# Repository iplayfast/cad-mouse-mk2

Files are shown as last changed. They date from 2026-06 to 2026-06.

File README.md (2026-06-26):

# CAD Mouse MK2

Watch the build video ↓

[](https://youtu.be/62xlzGs8LXA)

This is the second iteration of my DIY CAD Mouse, rebuilt to behave like a real 6DoF controller. It uses a custom PCB with three magnetic sensors, a 3D printed spring, and a redesigned enclosure that is smaller and easier to build.

  Build instructions → [Instructables](https://www.instructables.com/CAD-Mouse-MK2-a-6DoF-Space-Mouse-Using-Magnets)

<sub>⚠️ There have been several comments raising concerns about the longevity of the PETG spring. If it does not last as expected, a revision of the knob design will be needed.</sub>

## Linux Setup

After flashing the firmware, run the one-time setup script to configure spacenavd (the 6DoF motion driver) and the button mapper:

```bash
./linux-setup.sh
```

This script:
- Installs `spacenavd` and `xdotool`
- Writes `/etc/spnavrc` so spacenavd recognises the device by USB VID:PID
- Installs udev rules so the device is accessible without root
- Installs `spacemouse-buttons.py` as a systemd user service that maps button presses to keystrokes

After running it, plug in the mouse and wait a couple of seconds for the LED to turn green — the device is running its zero-calibration on startup.

### Button mapping

Button behaviour is configured in `~/.config/spacemouse/button-map.conf`. The file shipped with the repo maps:

| Button | App | Key(s) |
|---|-----|---|
| 1 | FreeCAD | `2` (top view) |
| 1 | * (all others) | `f` (fit/zoom all) |
| 2 | * | `5` (isometric view) |

Edit the file to match your preferred CAD application. Reload without restarting:

```bash
kill -HUP $(cat /tmp/spacemouse-buttons.pid)
```

Live log:

```bash
journalctl --user -fu spacemouse-buttons
```

Debug button events:

```bash
python3 ~/.local/bin/spacemouse-buttons.py --list-events
```

## Calibration

Because the three magnetic sensors are physically close together, each sensor responds to motion in every direction — not just the one you're moving. Without correction, pushing the puck sideways also produces spurious tilt and twist outputs. Calibration solves this by fitting a **6×9 decoupling matrix** that maps the raw 9-channel sensor readings (3 axes × 3 sensors) to clean 6-DoF outputs (TX, TY, TZ, RX, RY, RZ).

The fitted matrix is sent to the device over USB and saved to flash — **no reflashing required**. The device loads it automatically on every boot. `firmware/include/Calibration.h` is also updated as a compiled-in fallback for fresh firmware flashes.

You should recalibrate whenever you rebuild the mouse, swap a sensor, or notice persistent drift or cross-axis bleed-through.

### Requirements

- Python 3 with `numpy` (`pip install numpy`)
- The mouse flashed and plugged in, LED solid green (idle)

### Steps

1. From the project root, run:
   ```bash
   ./run_calibration.sh
   ```
2. The script walks you through **6 movements**, one per axis:

   | Step | Movement |
   |------|----------|
   | TX | Slide the puck **left and right** — translate only, no tilt or twist |
   | TY | Slide the puck **forward and back** — translate only, no tilt or twist |
   | TZ | Press the puck **straight down** then release — no tilt or sideways |
   | RX | **Tilt front-to-back** — front edge dips then rises |
   | RY | **Tilt left-to-right** — left edge dips then rises |
   | RZ | **Twist clockwise then counterclockwise** around the puck's centre |

3. For each step: press **Enter** to open the live monitor, make the movement slowly (stay well under the ±350 output limit), then press **Q** to stop recording.
4. After all 6 logs are collected, `calibrate.py` fits the matrix and prints a cross-talk table. Any axis bleeding more than 50% into another is flagged — if you see warnings, recollect that axis's log.
5. The new matrix is sent to the device immediately and takes effect without restarting. It is also written to `firmware/include/Calibration.h`.

### How it works

**Data collection** — `monitor.py` polls HID feature report ID 4 via the Linux `hidraw` interface (`HIDIOCGFEATURE` ioctl) at ~50 Hz. The firmware fills this report with the 9 baseline-subtracted sensor delta values each motion loop cycle. Motion axis values (TX–RZ) are read from the standard HID input report. No serial port or special firmware build is required.

**Matrix fitting** — `calibrate.py` uses least-squares regression (`numpy.linalg.lstsq`) across all six labeled movement logs simultaneously to find the 6×9 matrix that best predicts the intended single-axis output from the 9 sensor deltas. Fitting all axes together lets the solver distinguish shared sensor patterns that belong to one DoF from those that belong to another.

**Sending the result** — after fitting, `calibrate.py` writes the matrix to the device via HID output report ID 5 (`write()` on the hidraw device). The firmware applies the matrix immediately and saves it to LittleFS flash. On every subsequent boot, the saved matrix is loaded automatically. If no saved matrix exists (e.g. after first flash), the firmware falls back to the matrix compiled into `Calibration.h`.

[][cc-by-nc-sa]

[][cc-by-nc-sa]

[cc-by-nc-sa]: http://creativecommons.org/licenses/by-nc-sa/4.0/
[cc-by-nc-sa-image]: https://licensebuttons.net/l/by-nc-sa/4.0/88x31.png
[cc-by-nc-sa-shield]: https://img.shields.io/badge/License-CC%20BY--NC--SA%204.0-lightgrey.svg

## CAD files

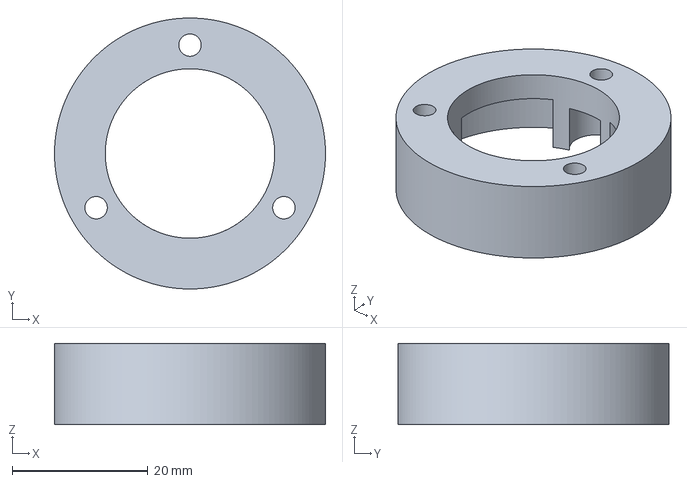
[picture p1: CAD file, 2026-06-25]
enclosure/step/Magent8mmholder.3mf
40.0 x 40.0 x 12.0 mm

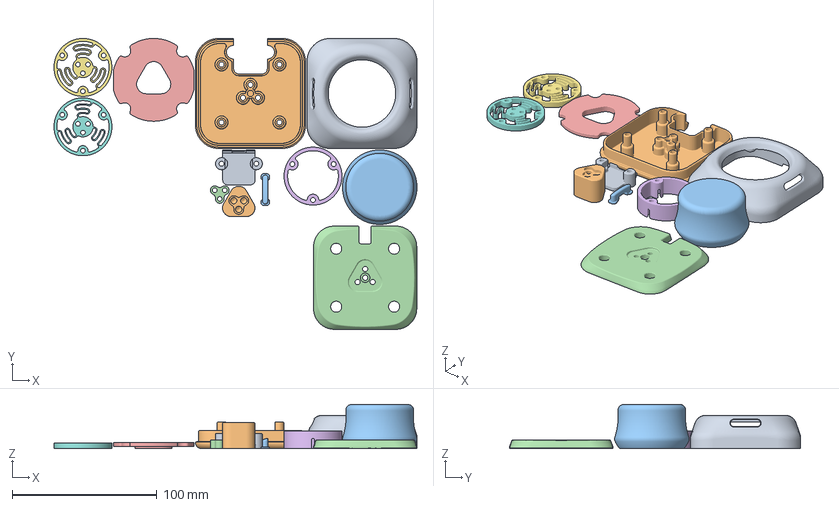
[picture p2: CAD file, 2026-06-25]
enclosure/stl/00_spring_1_0_mm_30_deg.3mf
250.7 x 201.0 x 30.5 mm
base_shell_top.stl
base_shell_bottom.stl
knob.stl
base_separator.stl
diffuser.stl
magnet_holder.stl
00_spring_1_0_mm_30_deg.stl
01_spring_0_8_mm_30_deg.stl
base_mcu_cover.stl
stem.stl
side_button.stl
spring_spacer.stl

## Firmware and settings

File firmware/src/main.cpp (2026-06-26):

#include <Arduino.h>
#include <LittleFS.h>

#include "CalibrationStore.h"
#include "Config.h"
#include "Controllers.h"
#include "StateMachine.h"

InputController inputController;
LEDController ledController;
SensorController sensorController;
MotionController motionController;
HIDController hidController;
TelemetryController telemetryController;

void setup() {
  hidController.begin();

  if (Config::ENABLE_TELEMETRY) {
    Serial.begin(115200);
    delay(200);
  }

  LittleFS.begin();

  inputController.begin();
  ledController.begin();
  sensorController.begin();
  motionController.reset();
  telemetryController.begin();

  // Load persisted calibration matrix if one has been saved.
  float matrix[6][9];
  if (CalibrationStore::load(matrix)) {
    motionController.setDecouplingMatrix(matrix);
  }

  stateMachine.changeState(&StateMachine::calibratingState);
}

void loop() {
  hidController.task();
  stateMachine.update();
}

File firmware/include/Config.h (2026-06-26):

#pragma once

#include <Arduino.h>

namespace Config {

const bool ENABLE_TELEMETRY = false;

// Hardware pins (XIAO RP2350)
const int PIN_RIGHT_BTN = D0;
const int PIN_LEFT_BTN = D2;
const int PIN_LED_DATA = D3;
const int PIN_LED_LS = D1;
const int PIN_MAG1_LS = D10;
const int PIN_MAG2_LS = D9;
const int PIN_MAG3_LS = D8;

// Samples for calibration offset
const int ZERO_SAMPLES = 200;

// Dead zones
const float DEAD_T = 16.0;
const float DEAD_R = 20.0;

// Smoothing
const float SMOOTH_TAU_S = 0.08;

// Final axis output range
const float AXIS_LIMIT = 350.0;

// RGB LEDs
const int LED_COUNT = 8;
const int LED_BRIGHTNESS = 40;
const unsigned long LED_IDLE_COLOR = 0x00FF00;
const unsigned long LED_CALIBRATING_COLOR = 0x0000FF;

// FSM timing
const long IDLE_SLEEP_TIMEOUT_MS = 2 * 60 * 1000;

}  // namespace Config

#include "Calibration.h"

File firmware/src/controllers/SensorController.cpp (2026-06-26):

#include "controllers/SensorController.h"

#include "Config.h"

using namespace ifx::tlx493d;

SensorController::SensorController()
    : mag1Sensor_(Wire, TLx493D_IIC_ADDR_A0_e),
      mag2Sensor_(Wire, TLx493D_IIC_ADDR_A0_e),
      mag3Sensor_(Wire, TLx493D_IIC_ADDR_A0_e) {}

void SensorController::powerOff(int pin) { digitalWrite(pin, LOW); }

void SensorController::powerOn(int pin) {
  digitalWrite(pin, HIGH);
  delay(5);
}

void SensorController::begin() {

  pinMode(Config::PIN_MAG1_LS, OUTPUT);
  pinMode(Config::PIN_MAG2_LS, OUTPUT);
  pinMode(Config::PIN_MAG3_LS, OUTPUT);

  // All three rails are pulled high in hardware, so force them all off first
  // before bringing sensors up one-by-one for address assignment.

  powerOff(Config::PIN_MAG1_LS);
  powerOff(Config::PIN_MAG2_LS);
  powerOff(Config::PIN_MAG3_LS);
  delay(5);

  Wire.begin();
  Wire.setClock(400000);

  powerOn(Config::PIN_MAG1_LS);
  mag1Sensor_.begin(true, false, false, true);
  mag1Sensor_.setIICAddress(TLx493D_IIC_ADDR_A2_e);
  mag1Sensor_.setSensitivity(TLx493D_EXTRA_SHORT_RANGE_e);
  delay(10);

  powerOn(Config::PIN_MAG2_LS);
  mag2Sensor_.begin(true, false, false, true);
  mag2Sensor_.setIICAddress(TLx493D_IIC_ADDR_A1_e);
  mag2Sensor_.setSensitivity(TLx493D_EXTRA_SHORT_RANGE_e);
  delay(10);

  powerOn(Config::PIN_MAG3_LS);
  mag3Sensor_.begin(true, false, false, true);
  mag3Sensor_.setSensitivity(TLx493D_EXTRA_SHORT_RANGE_e);
  delay(10);
}

bool SensorController::readRaw(float out[9]) {
  double mag1x = 0, mag1y = 0, mag1z = 0, temp1 = 0;
  double mag2x = 0, mag2y = 0, mag2z = 0, temp2 = 0;
  double mag3x = 0, mag3y = 0, mag3z = 0, temp3 = 0;

  const bool ok1 = mag1Sensor_.getMagneticFieldAndTemperature(&mag1x, &mag1y, &mag1z, &temp1);
  const bool ok2 = mag2Sensor_.getMagneticFieldAndTemperature(&mag2x, &mag2y, &mag2z, &temp2);
  const bool ok3 = mag3Sensor_.getMagneticFieldAndTemperature(&mag3x, &mag3y, &mag3z, &temp3);

  if (!ok1 || !ok2 || !ok3) {
    return false;
  }

  // MAG1 = bottom, MAG2 = top left, MAG3 = top right.
  out[0] = mag1x;
  out[1] = mag1y;
  out[2] = mag1z;
  out[3] = mag2x;
  out[4] = mag2y;
  out[5] = mag2z;
  out[6] = mag3x;
  out[7] = mag3y;
  out[8] = mag3z;
  return true;
}

void SensorController::beginCalibration() {
  calibrationActive_ = true;
  calibrationDone_ = false;
  calibrationSamples_ = 0;
  calibrationSampleStarted_ = false;
  lastCalibrationSampleMs_ = 0;
  for (int i = 0; i < 9; i++) {
    calibrationSum_[i] = 0.0;
  }
}

void SensorController::updateCalibration() {
  if (!calibrationActive_) {
    return;
  }

  const unsigned long now = millis();
  if (calibrationSampleStarted_ && (now - lastCalibrationSampleMs_) < 10) {
    return;
  }
  calibrationSampleStarted_ = true;
  lastCalibrationSampleMs_ = now;

  float raw[9] = {};
  if (!readRaw(raw)) {
    return;
  }

  for (int i = 0; i < 9; i++) {
    calibrationSum_[i] += raw[i];
  }

  calibrationSamples_++;
  if (calibrationSamples_ < Config::ZERO_SAMPLES) {
    return;
  }

  for (int i = 0; i < 9; i++) {
    baseline_[i] = calibrationSum_[i] / Config::ZERO_SAMPLES;
  }

  calibrationActive_ = false;
  calibrationDone_ = true;
}

bool SensorController::calibrationDone() const { return calibrationDone_; }

const float* SensorController::baseline() const { return baseline_; }

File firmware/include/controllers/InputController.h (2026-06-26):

#pragma once

#include <Arduino.h>
#include <AceButton.h>

class InputController {
 public:
  InputController();
  void begin();
  void update();

  uint16_t buttonBits() const;
  bool takeCalibrationRequest();
  bool takeActivity();

 private:
  static void handleButtonEvent(ace_button::AceButton* button, uint8_t eventType,
                                uint8_t buttonState);
  void onButtonEvent(ace_button::AceButton* button, uint8_t eventType);
  bool areBothPressed() const;

  ace_button::AceButton leftBtn_;
  ace_button::AceButton rightBtn_;

  bool calibrationRequested_ = false;
  bool hadActivity_ = false;
  bool bothHeldActive_ = false;
  unsigned long bothHeldStartMs_ = 0;
  bool calibrationHoldFired_ = false;
  bool leftPressed_ = false;
  bool rightPressed_ = false;

  static InputController* instance_;
};

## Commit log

2026-06-25 changed controller to rp2350, updated lights to work with the new controller
    [00_spring_1_0_mm_30_deg.3mf, Magent8mmholder.3mf]
2026-06-26 Add sensor decoupling matrix to fix DOF cross-talk
    The hand-coded translation/rotation formulas caused large spurious outputs
    on Z, Rx, Ry during pure XY translation (confirmed via log analysis).
    Replaces the formulas with a 6x9 calibration matrix (Config::DECOUPLING_M)
    fitted from per-DOF calibration movements using least squares, so each axis
    responds only to its intended physical input.
    Changes:
    - MotionController: matrix multiply replaces hand-coded formulas
    - Calibration.h: generated file holding the matrix (included by Config.h)
    - TelemetryController: now emits 9 baseline-subtracted sensor deltas
    (s0x..s2z) alongside motion values, for use by calibration tooling
    - monitor.py: logs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
    [Config.h, TelemetryController.cpp]
2026-06-26 Add calibration docs and update calibration tooling
    Documents the purpose of the sensor decoupling matrix, step-by-step
    calibration instructions, and how the least-squares fit works in README.md.
    Includes the updated run_calibration.sh script and regenerated Calibration.h.
2026-06-26 Fix dead-zone latency, dead constants, I2C error handling, and sentinel bugs
    - Remove double dead-zone: hardZero() on output was zeroing motion while
    the lowpass filter ramped up from 0, causing a sticky delay at the start
    of every movement. Output is now just clampf(filt_[i], ±AXIS_LIMIT).
    - Delete unused GAIN_T, GAIN_R, SIGN_AXIS from Config.h (pre-decoupling-matrix
    leftovers with no callers).
    - Default ENABLE_TELEMETRY to false so production builds don't ship with
    serial output and a 200ms startup delay.
    - Make readRaw() return bool and check TLx493D read success; IdleState and
    updateCalibration now skip the frame/sample on I2C failure.
    - Replace millis()==0 sentinels with expl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
    [Config.h, InputController.h, LEDController.cpp]
2026-06-26 Add per-app button-to-key mapper for Linux
    Adds spacemouse-buttons.py, a hidraw-based listener that fires xdotool
    key sequences when a button is pressed, matched against the active window
    title. Reads from /dev/hidrawN directly (non-exclusive) so it coexists with
    spacenavd which holds an exclusive grab on the evdev node.
    Key design decisions:
    - buffering=0 on hidraw open — preserves one-report-per-read kernel guarantee
    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
2026-06-26 Add HID feature reports, LittleFS calibration persistence, no reflash needed
    - HID descriptor gains report ID 4 (feature: 9 sensor-delta floats) and
    report ID 5 (output: 6×9 calibration matrix). TinyUSB callbacks route
    GET/SET report to HIDController.
    - MotionController.setDecouplingMatrix() lets the matrix be updated at
    runtime without reflashing. Falls back to compiled-in Calibration.h.
    - CalibrationStore reads/writes the matrix to LittleFS flash so it
    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
2026-06-26 Update README: Linux setup, button mapping, HID-based calibration workflow
    - Add Linux Setup section covering linux-setup.sh, spacenavd, and the
    button mapper (config, reload, debug commands).
    - Update Calibration section: remove pyserial requirement and reflash
    step; explain that the matrix is sent to the device over USB and
    persisted to LittleFS flash.
    - Expand "How it works" to describe HID feature report polling, matrix
    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

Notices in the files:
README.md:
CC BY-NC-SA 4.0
